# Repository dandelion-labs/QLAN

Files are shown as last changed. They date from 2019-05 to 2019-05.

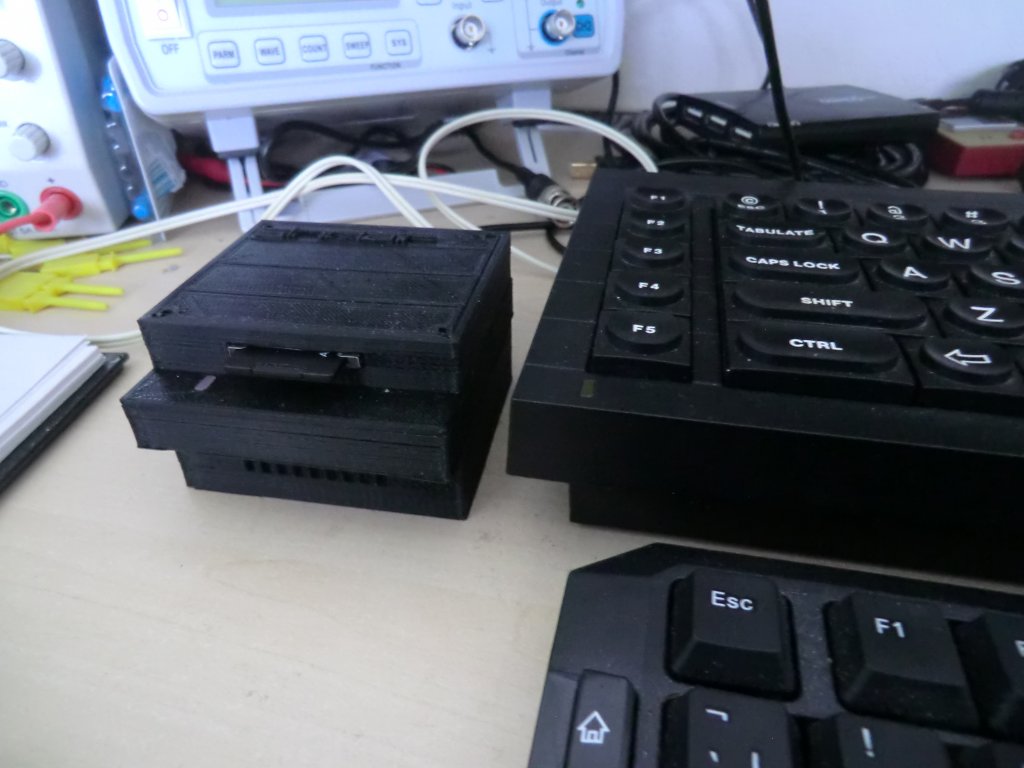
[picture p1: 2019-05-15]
3D_printed_case/CIMG0689.JPG

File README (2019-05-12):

Simple Sinclair QL Network File Server
(C) Jason Lucas 2019

This is a work in progress. It may contain bugs. Use with caution.

Provides an inexpensive way of transferring data to and from a QL using
the QL network interface.

The source code can be simply compiled using the Arduino IDE.

Notes:

Only one file can be opened at once.

Executable files will need a 15 byte file header added to the start of the file

Some versions of Toolkit 2 have a bug in the LOAD command, incorrectly requiring BASIC programs
to have a file header - A fix for this has been provided an can be activated/deactivate by setting
the useTK2Fix variable in the source code (default: true)

In some combinations of Toolkit 2 and Minerva ROM, networking does not work correctly - either update your ROMS
to the latest version, or either disable TK2 or Minerva.

Commands:

There are two versions of the commands code - one just as SuperBASIC procedures (net)
and one compiled as a QLiberator extension (net_obj). To use the latter, you will need a copy of
the QLiberator runtime (QLib_run)
An example boot file is included to load the QLib extension version of the commands

NFILE "filename"    - sets the currently active SD file
NDIR                - view the current SD directory
NDEL "filename"     - delete a file
NCHDIR "path"       - change the current directory
NMKDIR "path"       - create a new directory
NRMDIR "path"       - delete a directory (it must be empty)
NMOVE "file1" "file2" - move a file

Saving and loading files:

Once the filename has been set using the NFILE command,
files can be loaded/saved/executed using the network address 63

e.g
Load a BASIC file:

NFILE "somefile"
LOAD neti_63

Save a BASIC file:

NFILE "somefile"
SAVE neto_63

Execute a file:

NFILE "somefile"
EXEC_W neti_63

Save a screenshot

NFILE "somefile"
SBYTES neto_63,131072,32768

Load a screenshot

NFILE "somefile"
LBYTES neti_63,131072

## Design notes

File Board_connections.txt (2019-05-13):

Board connections

STM32F103C "Blue Pill"

Pin     Connection

PB12    Debug (optional)
PB13    Activity LED (optional)
PB14    Network Data Out
PB15    Network Data In

NRST    Reset button (to GND)

SPI Bus (PA4,PA5,PA6,PA7) - SPI SD Card Module

Arduino Nano

14 (A0) Debug (optional)
15 (A1) Activity LED (optional)
16 (A2) Network Data Out
17 (A3) Network Data In

RESET   Reset Button (to GND)

SPI Bus (10,11,12,13) - SPI SD Card Module

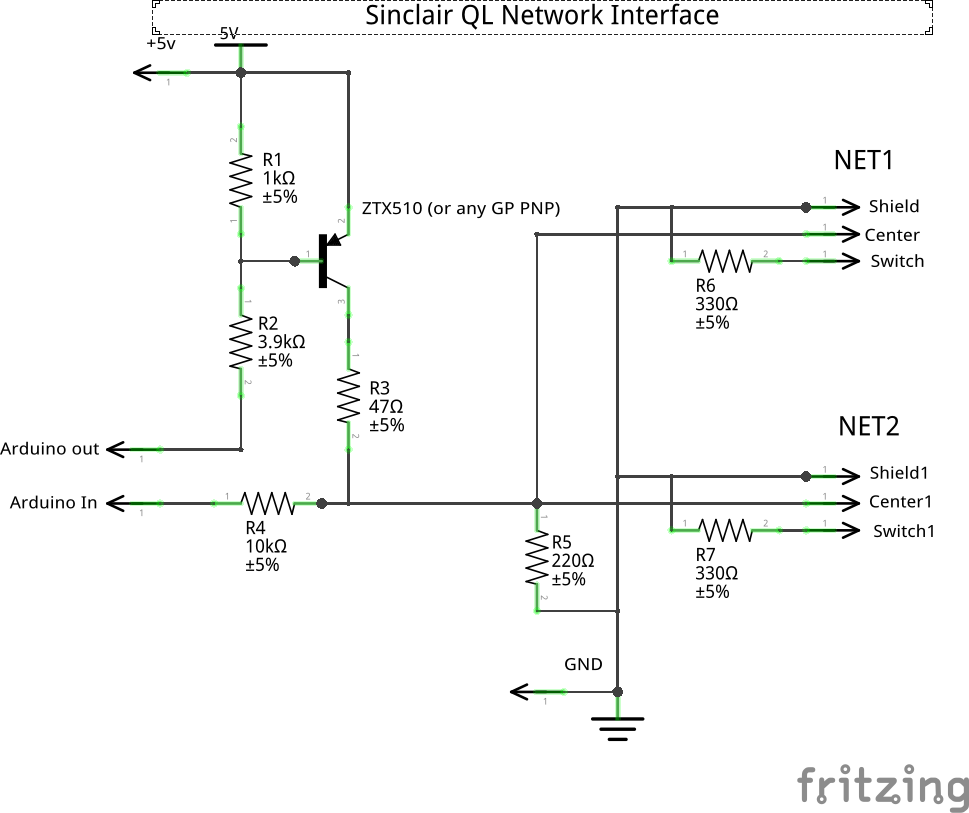
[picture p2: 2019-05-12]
QLNet_interface_schem.png

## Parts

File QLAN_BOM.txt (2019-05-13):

Bill of materials

1x STM32F103C "Blue Pill" module OR Ardunio Nano (not tested)
1x SPI SD Card module (search ebay!)
1x LED + approprate resistor (optional)
1x PNP transistor (ZTX510 or equiv)
1x 1k Resistor
1x 3.9K Resistor
1x 47R Resistor
1x 10K Resistor
1x 220R Resistor
2x 330R Resistor
2x 3.5mm Mono jack sockets
1x Small momentary push switch (for reset)

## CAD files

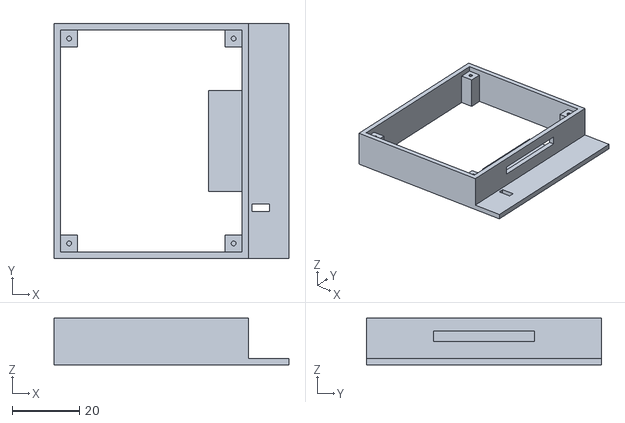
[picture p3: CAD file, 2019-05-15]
3D_printed_case/QL_FS_top.stl
70.0 x 70.0 x 14.0

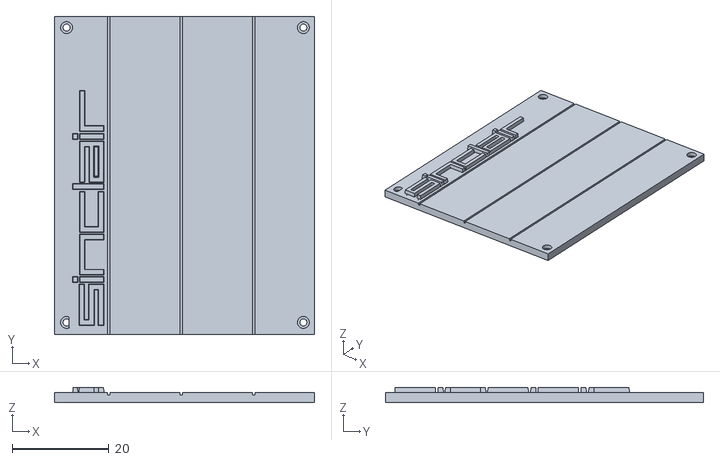
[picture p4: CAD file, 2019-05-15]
3D_printed_case/QL_FS_lid.stl
53.8 x 65.8 x 3.00

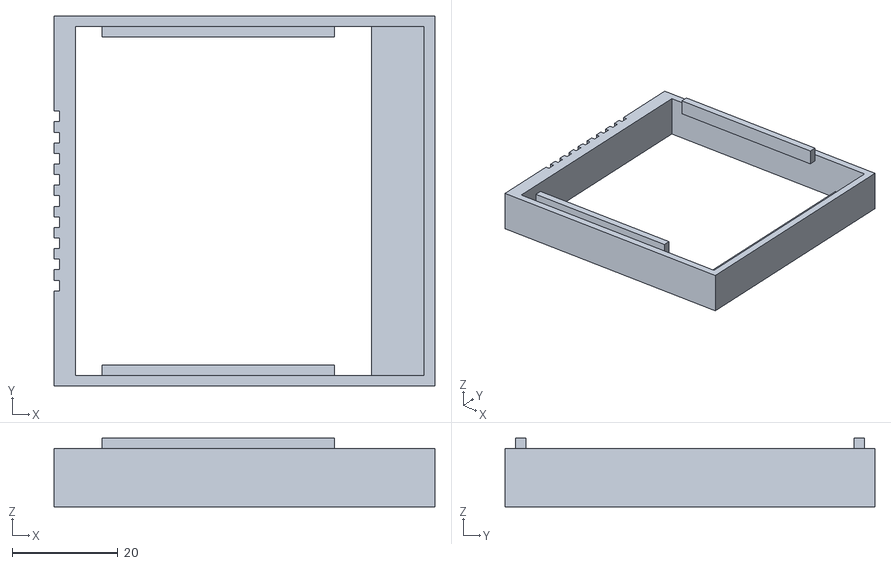
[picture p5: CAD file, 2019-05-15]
3D_printed_case/QL_FS_middle.stl
72.0 x 70.0 x 13.0

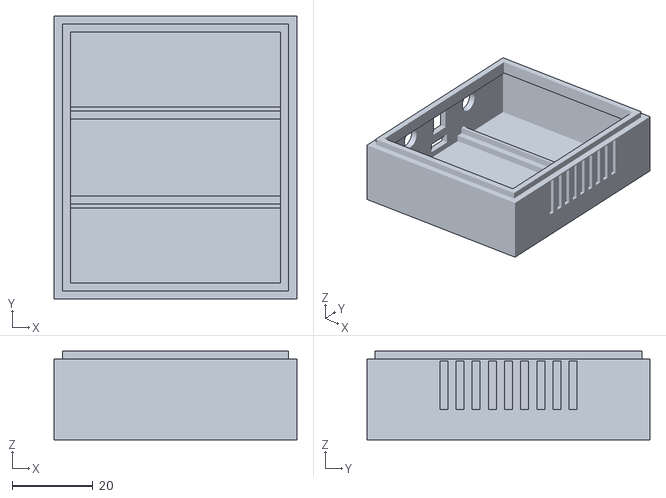
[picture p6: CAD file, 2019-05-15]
3D_printed_case/QL_FS_bottom.stl
60.0 x 70.0 x 22.0

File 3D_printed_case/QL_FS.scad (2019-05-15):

//QL Fileserver Case

translate([0,-35,0]){
    bottom();
    translate([-2,0,20]) middle();
    translate([0,2,31]) top();
    translate([2,2,43]) lid();
}



module bottom(){
    difference(){
       cube([60,70,20]);
        translate([2,2,2]) cube([55,66,18]);
        translate([-1,31,4]) BluePill_usb();
        translate([-1,20,14]) jack();
        translate([-1,50,14]) jack();
        translate([-1,32,10]) reset_button();
        translate([59,18,7.5]) vent_slot();
    }
    difference(){
        translate([2,2,18]) cube([56,66,4]);
        translate([4,4,18]) cube([52,62,5]);
    }
    translate([2,22.5,2]) BluePill_mount();
    
}

module middle(){
    difference(){
        cube([72,70,11]);
            translate ([4,2,2]) cube([66,66,9]);
            translate([4,2,0]) cube([56,66,18]);
            translate([-0,18,0]) vent_slot_back();
    }
   translate([9,2,9])  cube([44,2,4]);
   translate([9,66,9])  cube([44,2,4]);
}

module top(){
    difference(){
        translate([0,-2,0]) cube([70,70,2]);
        translate([2,0,0]) cube([54,66,2]);
        translate([59,12,-8]) led();
    }
    difference(){
        translate([0,-2,2]) cube([58,70,12]);
        translate([2,0,0]) cube([54,66,15]);
        translate([54,18,7]) sdslot();
    }
    translate([46,18,3]) cube([10,30,2]);
    translate([2,0,0]) lid_mounting();
    translate([2,61,0]) lid_mounting();
    translate([51,0,0]) lid_mounting();
    translate([51,61,0]) lid_mounting();
}

module lid(){
    difference(){
       cube([53.8,65.8,2]);
        translate([2,0,0])  lid_hole();
        translate([2,61,0]) lid_hole();
        translate([51,0,0]) lid_hole();
        translate([51,61,0]) lid_hole();
        for(a=[11:15:50]) translate([a,0,1.5]) #cube([0.5,66,0.5]);
       
    }
    translate([7,26,3]) logo();
}

module logo(){
    rotate([0,0,90])
    scale([0.1, 0.1, 0.01])
    surface(file = "sinclair-logo.png", center = true, invert = true);
}

module BluePill_mount(){
    cube([55,3,2]);
    cube([55,1,4]);
    translate([0,24,0]) cube([55,1,4]);
    translate([0,22,0]) cube([55,3,2]);
}

module BluePill_usb(){
    #cube([5,8,3]);
}

module lid_hole(){
    #translate([0.5,2.5,0]) {
        cylinder(h=2,d=1.5,$fn=10);
        translate([0,0,1]) cylinder(h=1,d=2.5,$fn=20);
    }
}

module lid_mounting(){
    difference(){
        cube([5,5,12]);
        #translate([2.5,2.5,7]) cylinder(h=5,d=1.5,$fn=10);
    }
}
module sdslot(){
    #cube([5,30,3.2]);
}

module led(){
    #cube([5.2,2.2,10]);
}

module jack(){
    #rotate([0,90,0]) cylinder(d=6.3,h=6,$fn=30);
}

module reset_button(){
    #cube([4,6.2,6.2]);
}
module vent_slot(){
    for(a=[0:4:35]) translate([0,a,0]) #cube([1,2,12]);
}

module vent_slot_back(){
    for(a=[0:4:35]){
        translate([0,a,0]) #cube([1,2,11]);
    }
}

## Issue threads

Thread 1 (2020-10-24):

no matching function for call to 'SdFat::open(String&, int)'

SM7I, 2020-10-24:
Using up2date Arduino IDE and libraries I get the following error when trying to compile:

no matching function for call to 'SdFat::open(String&, int)'

In the code where:
FD.handle=SD.open(fname,O_READ | O_WRITE | O_CREAT);

I realize that the code is way older than both my IDE and libs so I wonder if you could state which version(s) of libs I need to downgrade to in order to get this working, OR (if you like) adapt your code to the recent libs.

Either way, this is a great piece of work and since I´m a QL user as well as Spectrum user I'm really looking forward to get this going !

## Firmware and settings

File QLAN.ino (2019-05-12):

/**
 * STM32F103C "Blue Pill"
 * Sinclair QL network interface
 * 
 * Copyright (c) 2019 Jason Lucas / Dandelion Labs
 * 
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
 * 
 * QL standard network header format:
 * Please refer to the Toolkit2 documentation for
 * further details on the network protocol.
 * 
 * byte     Description
 * 0        Destination Station Number
 * 1        Sending Station Number
 * 2        LSB Block Number
 * 3        MSB Block Number
 * 4        Block type - 0 data, 1 last block (eof)
 * 5        Number bytes in block
 * 6        Data Checksum (simple addition)
 * 7        Header Checksum (simple addition)
 * 
 * PINS
 * 
 * PB13 - Debug Out
 * PB14 - Data Out (-ve logic)
 * PB15 - Data In
 * 
 * 
 * 
 */

 /*
  * TODO
  * 
  *
  * - TK2 broadcast mode
  */
  
 
//SD Card
#include <SPI.h>
#include <SdFat.h>

//Error Codes
#define E_OK 0 //OK
#define E_EOF 1 //End of file
#define E_NTS 2 //Block not for this station
#define E_TO 3 //Timeout error
#define E_MTO 4 //Maximum timeout retries exceeded
#define E_CMD 5 //Command received
#define E_CHK 6 //Checksum error
#define E_CON 7 //Network Contention error
#define E_FNF 8 //File not found
#define E_FZB 9 //File has zero bytes

//Timings (all in uS unless otherwise stated)
#define T_BIT 11  //Bit length 11
#define T_STOP 55 //Stop bits 55
#define T_ACT 22 //Network Active 22
#define T_HDGAP 150 //Gap between header ACK and data block 150
#define T_IBLK 3000 //Inter-Block gap 3000

//Commands
#define C_NFILE "aA" //Set currently active file - parameter: filename
#define C_NDIR "aB" //Show current directory listing - parameter: none
#define C_NDEL "aC" //Delete file - parameter: filename
#define C_NCHDIR "aD" //Change directory - parameter: dirname
#define C_NMKDIR "aE" //Make new directory - parameter: dirname
#define C_NRMDIR "aF" //Remove directory - parameter: dirname
#define C_NMOVE "aG" //Move file

SdFat SD;

class fileData{
  public:
    String fname="boot";
    File handle;
    boolean useTK2Fix=true;
};


fileData FD;


String command="",parameter=""; //Current command & parameter
String currentPath="/";
byte clientNETID=1; //Currently active client NETID (63-self inactive)

static byte NETID=63; //Station ID
static byte ScoutRetries=5; //Number of scout send retries before failure
static short Write_Retries=5;
short Read_Retries=50;

volatile boolean ignorePinTrig=true,pinTrigUp=false,pinTrigDown=false;

char Buf[256],Header[8];

void setup() {
  // put your setup code here, to run once:
  
  //Serial
  Serial.begin(115200);
  delay(2000);

  /* Generic STM32F103C board definition
   *Board definition fnames can be found by setting the compile verbose setting
   *& looking for the string after one of the -D compile options.
   *
   *E.G, Arduino nano  -DARDUINO_AVR_NANO
  */
  #ifdef ARDUINO_GENERIC_STM32F103C
    Serial.println("STM32F103C");
    pinMode(PB12,OUTPUT);//Debug pin
    pinMode(PB13,OUTPUT);//LED pin
    pinMode(PB14,OUTPUT);//Data Out - ***Inverted logic***
    pinMode(PB15,INPUT);//Data In
    digitalWrite(PB14,HIGH);
    #define INT_PIN PB15  //Hardware interrupt pin
    //Direct port access
    //Debug Pin
    #define SET_DEBUG_PIN GPIOB->regs->BSRR = 0b0001000000000000 //Debug set PB12
    #define CLR_DEBUG_PIN GPIOB->regs->BRR = 0b0001000000000000 //Debug clear PB12
    //LED Pin  
    #define SET_LED_PIN GPIOB->regs->BSRR = 0b0010000000000000 //LED set PB13
    #define CLR_LED_PIN GPIOB->regs->BRR = 0b0010000000000000 //LED clear PB13
    //Data Out Pin
    #define SET_DATA_PIN GPIOB->regs->BSRR = 0b0100000000000000 //set PB14
    #define CLR_DATA_PIN GPIOB->regs->BRR = 0b0100000000000000 //clear PB14
    //Data In Pin
    #define READ_DATA_PIN GPIOB->regs->IDR & 0b1000000000000000 //Read PB15
  #endif

  //Arduino NANO board definition
  #ifdef ARDUINO_AVR_NANO 
    Serial.println("ARDUINO NANO");
    pinMode(14,OUTPUT);//Debug pin
    pinMode(15,OUTPUT);//LED pin
    pinMode(16,OUTPUT);//Data Out - ***Inverted logic***
    pinMode(17,INPUT);//Data In
    digitalWrite(16,HIGH);
    #define INT_PIN  17 //Hardware interrupt pin
    //Direct port access
    //Debug Pin
    #define SET_DEBUG_PIN PORTC |= B00000001
    #define CLR_DEBUG_PIN PORTC &= ~B00000001
    //LED Pin    
    #define SET_LED_PIN PORTC |= B00000010
    #define CLR_LED_PIN PORTC &= ~B00000010
    //Data Out Pin
    #define SET_DATA_PIN PORTC |= B00000100 
    #define CLR_DATA_PIN PORTC &= ~B00000100
    //Data In Pin
    #define READ_DATA_PIN PINC & B00001000
  #endif

  //Net data in interrupt
  attachInterrupt(digitalPinToInterrupt(INT_PIN), pinTrig_isr, CHANGE);
  
  //Init SD card
  
  Serial.print("Initializing SD card...");
  if (!SD.begin(4)) {
    Serial.println("initialization failed!");
    while (1);
  } 
  
  Serial.println("initialization done.");
  Serial.println("Server Started.");
  //printDirectory("/");
  
}

void pinTrig_isr(){
  if(ignorePinTrig) return;
  if(READ_DATA_PIN){
    pinTrigUp=true;
  } else {
    pinTrigDown=true;
  }
}

void loop() {
  // put your main code here, to run repeatedly:
  //Serial.println("Sending broadcast");
  
  byte error=0;
  error=sendFile(FD.fname,clientNETID,NETID);
  if(error>=E_CON) {
    error=receiveFile(FD.fname);
    if(error==E_OK) Serial.println("Receive Success");
    if(error==E_CMD) execCommand();
  }
  
}

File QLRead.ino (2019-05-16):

/*
 * Standard QL Network Read routines
 * 
 * Read Data from QL
 * 
 */
byte receiveFile(String fname){
  byte error=0;
  short blockcount=0;
  //Clear input buffer
  for(byte count=0;count<255;count++) Buf[count]=0;
  
  
  //Main Read loop
  do{
    error=readBlock();
    //Save to SD card
    if((error==E_OK) || (error==E_EOF)){//Data is for this station
      if((Header[2]+Header[3])==0){//First block
        clientNETID=Header[1];
        if((Header[4]==1) && (Buf[0]=='C')){//Block is last block and first byte is 'C' - might be a command
          if(checkCommand()) return E_CMD; //Was a command - exit routine.
        }
        //Open file if no error
        SET_LED_PIN;
        char filename[37];
        fname.toCharArray(filename,37);
        SD.remove(filename);
        FD.handle=SD.open(fname,O_READ | O_WRITE | O_CREAT);
        if(!FD.handle){
          Serial.println("File error");
          return E_FNF;
        }
      }
      //Serial.print("Block: ");
      //Serial.println(blockcount);
      //blockcount++;
      FD.handle.write(Buf,Header[5]); 
    }
  } while ((error==E_OK) || (error==E_CHK));
  if(error==E_EOF) error=E_OK; //Report EOF as Success
  
  //Close File
  FD.handle.close();
  
  //Read_Retries=5;
  CLR_LED_PIN;
  return error;
}

byte readBlock(){
  byte chksum=0;
  short retries=0;
  while(waitScout()){
    retries++;
    if(retries==Read_Retries) return E_TO;//Timeout
  }
  //Serial.print("Retries: ");
  //Serial.println(retries,DEC);
  //Read header
  for(byte count=0;count<7;count++){
    Header[count]=readByte();
    chksum+=Header[count];
  }
  
  //Header Checksum
  Header[7]=readByte();
  if(chksum!=Header[7]) return E_CHK; //Checksum error
  
  if(Header[0]!=NETID) return E_NTS; //Block not for this station. Also ignore broadcast (NETID 0) blocks
  sendACK();
  //Read data
  
  chksum=0;
  for(byte count=0;count<Header[5];count++){
    Buf[count]=readByte();
    chksum+=Buf[count];
  }
  //Data Checksum
 if(chksum!=Header[6]) return E_CHK; //Checksum error
  
  sendACK();
  return Header[4];//E_OK(0) if more data, E_EOF(1) if EOF
}

byte readByte(){
  byte outData=0;
  boolean inData=0;
  unsigned long timeout=micros();
  pinTrigDown=false;//reset trig pin
  ignorePinTrig=false;
  while(!pinTrigDown){
    if(micros()>timeout+200){
      ignorePinTrig=true;  
      return E_TO;  //Timeout here will cause checksum error 
    }
    
   };
  ignorePinTrig=true;
  //debugPin();
  noInterrupts();
  delayMicroseconds(T_BIT);
  for(byte count=0;count<8;count++){
    //SET_DEBUG_PIN;
    inData=READ_DATA_PIN;
    outData+=(inData<<count);
    //CLR_DEBUG_PIN;
    delayMicroseconds(T_BIT);
  }
  delayMicroseconds(20);
  interrupts();
  return outData;
}

byte waitScout(){
  //debugPin();
  unsigned long timeout=micros();
  pinTrigUp=false;  //Enable pin interrupt to detect contention during wait phase
  ignorePinTrig=false;
  while(micros()<(timeout+T_IBLK)){};//3ms wait
  ignorePinTrig=true;
  if(pinTrigUp) return E_CON; //Contention detected

  
  pinTrigUp=false;//reset trig pin
  ignorePinTrig=false;
  while(!pinTrigUp){
     if(micros()>timeout+10000){//Timeout
      ignorePinTrig=true;  
      return E_TO; 
     }
    };
  ignorePinTrig=true;
  //debugPin();
  delayMicroseconds(500);
  return E_OK;
}

void sendACK(){
  //Set net active
  noInterrupts();
  delayMicroseconds(T_ACT*2);
  CLR_DATA_PIN;
  delayMicroseconds(T_ACT);
  SET_DATA_PIN;
  writeByte(1);
  interrupts();
  debugPin();
  
}

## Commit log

2019-05-12 Rename file, Added Arduino Nano support, added schematic
    Ardunio Nano support not tested yet.
2019-05-12 Updateds README, Added BOM,SuperBASIC commands
2019-05-13 Added board connections,updated BOM
2019-05-15 Added .scad,.stl files for 3D printed case
    [QL_FS.scad, QL_FS_bottom.stl, QL_FS_lid.stl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]
2019-05-16 Bug fix: receiveFile() not correctly overwriting save file
    Overwriting file was done by seeking to start of file & write new data -
    if the new file was shorter than the original, then end of the old file
    would not be overwritten, causing various errors when attempting to load
    file onto the QL.
    Routine now deletes original file before re-writing data.
    [QLRead.ino]
